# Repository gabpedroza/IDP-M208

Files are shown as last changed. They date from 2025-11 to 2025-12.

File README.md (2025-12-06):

# M208 IDP repository
Please read this file for important setup instructions

This branch has the code that actually ran in the robot, which can be read in /IDP/modules. The file graph_model.py is an exception: it has about 7 lines that were reconstructed from memory, since these very last changes were not saved. They are very likely to be faithful.
## Prerequisites
- Thonny
- Git

## Setup Instructions
### Thonny
- Download Thonny from https://thonny.org/
- Open Thonny > bottom right > Select Interpreter > MicroPython (Raspberry Pi Pico)

### VSCode
- Unsure if this works.
- To setup:
`code --install-extension ms-python.python`
`code --install-extension visualstudioexptteam.vscodeintellicode`
`code --install-extension ms-python.vscode-pylance`
`code --install-extension paulober.pico-w-go`

- To launch: `export PICO_SDK_PATH=/home/pi/pico/pico-sdk` -->
`code`

## Version Control Practices
1. Commit every significant change. If unsure, err on the side of committing too much rather than too little.
2. Add a helpful commit message to EVERY commit so that people know what is going on/what has been changed.
3. Work on your own branch and resolve conflicts carefully before merging into `main`.

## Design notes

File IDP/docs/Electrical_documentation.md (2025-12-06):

## Motors
### Linear actuator
The motors connections are wired so that the red wire should connect to the pin labelled 1. Otherwise, it is plug and play.
## Sensors
### I2C ports testing
Using the very reliable VL53L0X, all I2C pin pairs (not connected to motors) were tested. All of them work, besides:
- Pins 31 & 32 (GP 26 & GP 27) don't seem to work. The sensor spits an error:
```
Traceback (most recent call last):
  File "<stdin>", line 33, in <module>
  File "<stdin>", line 11, in test_vl53l0x
  File "libs/VL53L0X/VL53L0X.py", line 114, in __init__
  File "libs/VL53L0X/VL53L0X.py", line 164, in init
  File "libs/VL53L0X/VL53L0X.py", line 149, in _flag
  File "libs/VL53L0X/VL53L0X.py", line 145, in _register
  File "libs/VL53L0X/VL53L0X.py", line 137, in _registers
OSError: [Errno 110] ETIMEDOUT
```

Since both I2C channels seem to work, this shouldn't be a problem.

`TODO`: check if pins 31 & 32 work with other sensors.
### VL53L0X ToF distance sensor (left because good)
It works out of the box. The I2C address is 0x29, which conflicts with TCS3462S. Hence it is a good strategy to turn off the colour sensor when it's not in use.

The sensor seems to have a constant offset of about 25mm (that is, the real distance is generally 25mm less than it detects), but is otherwise more accurate than my measurements. It can detect distances reliably from 4cm all the way to about 17.5cm, assuming its offset is consistent (which seemed very likely).
### TCS3472S colour sensor
It needs pull-up resistors on SDA (green) and SCL; $\mathrm{2.2k}\Omega$ works. Its address is 0x29 (you can tell the pull up is not working if the Pico picks up an address that is not 0x29 = 41).

The sensor needs to be around 3mm from the box (ideally closer but not further) to reliably detect the colour of it.

The sensor was extremely volatile as tested. The numbers were stable, but it would recurrently disconnect from I2C, hence, a fault-tolerant code is needed, e.g. (adapted from handout):

```python
from machine import Pin, SoftI2C, I2C
from libs.tcs3472_micropython.tcs3472 import tcs3472
from utime import sleep

def test_tcs3472():
    i2c_bus = I2C(id=0, sda=Pin(8), scl=Pin(9)) 
    tcs = tcs3472(i2c_bus)

    while True:
        try:
            print("Light:", tcs.light())
            print("RGB:", tcs.rgb())
            sleep(1)
        except:
            try:
                tcs = tcs3472(i2c_bus)
            except:
                sleep(1)

if __name__ == "__main__":
    test_tcs3472()
```
`TODO`: tests other pull up values, test colour range with the proper blocks.
### TTL line sensors
They are plug and play. They require pull-down resistors, which the Pico can supply internally (`Pin(#pin_number#, Pin.IN, Pin.PULL_DOWN)` from the handout).

They (number is at the moment codified by the number of knots on their wires) were measured to have the following characteristics (distances measured from the PCB):

1. TTL #1 could detect the back of the breadboard from a 2.7cm distance.
2. TTL #2 could detect the back of the breadboard from a 2.9cm distance.
3. TTL #3 could detect the back of the breadboard from a 2.65cm distance.
4. TTL #4 could detect the back of the breadboard from a 2.8cm distance.

The sensors light up with a blue LED on their back when they see something white. This could potentially be useful when diagnosing robot problems.
### TMF8701 Distance sensor (front)
It works out of the box, with I2C address 65.
We are using it in proximity mode as it's being used as the front sensor for detecting the distance to the box. The robot will need to move a bit further after the sensor reports distance being zero as it can't actually detect low distances below 5mm. Colour sensor must be 3mm away from the box to work

It has three sensing modes: proximity, distance, and combine. It also supports built-in calibration. 

1. In the proximity mode, the sensor can only detect object up to 9cm from it. It was most accurate around the 5cm mark, and it was found it doesn't have a constant offset (though it didn't deviate by more than 7mm). It could detect objects within that accuracy all the way to basically touching the sensor.

2. In the distance mode, it could detect objects up to about 17cm away. Again, the offset seemed to shift with distance, and it seemed most accurate at the 8cm mark. The offset could vary my more than 1.5cm. It could detect objects well up to touching distance.

3. In the hybrid (combined) mode, it seemed to be no better than the distance mode. 8cm mark looked accurate, but it had varying offset elsewhere. The range seems to be longer than the proximity mode, but shorter than the distance mode.

### Ultrasonic sensor (right because bad)
The sensor is plug and play, but must be connected to a port with ADC. Adapting the code from [here](https://docs.micropython.org/en/latest/rp2/quickref.html) and [here](https://wiki.dfrobot.com/URM09_Ultrasonic_Sensor_(Gravity_Analog)_SKU_SEN0307), it can thus be written:
```python
from machine import ADC, Pin
from time import sleep
adc = ADC(Pin(28))     # create ADC object on GP number
        
while True:
    msum = 0
    for _ in range(10):
        msum += adc.read_u16()*390/65535 #12-bit ADC
        #390 seems to give accurate numbers 
        sleep(0.04) #below the 30 Hz max polling rate
    print(msum/10)

```
The sensor fluctuates a lot and very drastically between measurements (e.g. by 3cm). By averaging e.g. the last 10 measurements as above, the sensor still has acceptable throughput and is much more stable. 

Since it behaves in such a simple way, the error is strongly dependent on the multiplying constant chosen. `3900` gives about 5 mm of error from 40mm all the way to 24mm. This can be made better with finer tuning. Tuning has not been done yet.
Thresholds for detecting boxes on the track reliably have also not been done and need to be tuned once we are ready to use the sensor.

## LED circuit Biasing
### Red LED and colour sensor with BJT
- 3.3V output from Pico servo port (pins 2 and 3) is VDD
- Pulldown resistor 10k between emitter and input
- 2.7k resistor at base
- 150Ohm resistor at collector
- colour sensor goes in parallel with LED + collector resistor
- SDA and SCL have 2.2k pullup resistors

## Amber LED Oscillator circuit
- Use CD4093B as a schmidt trigger.
- Connect Pin 1 to GPIO output of Pico
- Pin 14 to Vcc (3.3V) and pin 7 to GND
- Pin 2 to 120Ohm resistor in series with amber LED and ground
- 580k resistor betweeen pins 3 and 2.
- 2 3.3uF capacitors between pin 2 and GND.
- The time constant is proportional to the product of the 580k resistor and the effective capacitance.

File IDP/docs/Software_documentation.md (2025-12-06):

# Software
1. [Algorithms](#algorithms)
    1. [General outline](#general-outline)
    2. [Sensing lines](#sensing-lines)
    3. [PID](#pid)
    4. [Radical turn](#radical-turn)
    5. [Appendix: the BFS algorithm](#appendix-the-bfs-algorithm) 

2. [Class specifications](#class-specifications)
    1. [Junction](#junction)
    2. [Plant](#plant)
    3. [Follower](#follower)
## Algorithms
### General outline
The robot operates in 3 clearly distinct modes.
1. "ground": It circles around the ground floor of the arena, looking for boxes. It does so by checking with the left-hand side distance sensor. This is achieved through the `Follower.hunt_box` method (though it doesnt have a loop itself).
2. "second": It goes back and forth in the second floor, looking for boxes. In this case, it has to use sensors on both sides. This is also achieved through the `Follower.hunt_box` method.
3. Delivery: after picking up a box with `Follower.pick_ground_box`, follows a breadth-first algorithm to go between two specified nodes, using the `Follower.deliver_box` method. 

It starts on the ground mode, and momentarily switches to delivery mode on each detected box. After a set number of boxes are picked up and delivered, it switches to second mode, and goes back to delivery whenever it finds a box. After finding the last boxes, it delivers itself to the start area through the delivery mode. It auto-detects when to go home inside the `Follower.hunt_box` method, and returns with the method `Follower.go_home`. 
### Sensing lines
The robot averages out a set of line measurements to produce a list of values on which to act. White and black are hence defined through a threshold. This smoothes out possible small glitches in the sensors. 

The two middle sensors only care about PID (straight line following), as written in `Follower.pid`. The two external sensors only care about node detection. Node detection is a two-step process, as written in `Follower.detect_radical_turn`:
 1. If any external sensor detects something white, it records that. The node has not yet been detected.
 2. After a specified period of time since this first detection (currently 150ms), it checks again, with both sensors. The outcome of this measurement gives the output of node detection.

This is to ensure even a misaligned robot can detect a cross (+) pattern correctly.  
### PID
It's actually a poportional controller for following straight lines. It's executed whenever a node is not detected.
### Radical turn
A radical turn is the behaviour of the robot upon detecting a node. It doesn't necessarily involve a physical turn; it just means the robot turns off its PID mind and follows whatever is specified for that node in that mode, as descrbed in the modes dictionary. 
### Appendix: the BFS algorithm
A graph is a set of nodes connected by edges (which are, in our case, straight segments). The node picture of the arena naturally gives way to thinking of it as a graph.

Given two nodes in a graph, the problem of finding the best path between them, using edges as roads, is non-trivial. The breadth-first algorithm finds the path that minimises path length as computed by the number of nodes in it. It does so as follows, using the help of a queue (all nodes start with infinite distance):
1. Given a node $A$, check all of its neighbours $B_i$
2. If some node $B_j$ has infinite distance, update its distance as $d(B_j) = d(A) + 1$ and push it into the queue.
3. After all neighbouring nodes $B_j$ have been checked, take the first node in the queue to be $A$ and go back to step 1.

The algorithm is kickstarted by picking the starting node to be $A$ and setting its distance to be 0. It then proceeds until the queue is empty. One can picture it as a contagious process where nearer nodes are infected first; thus it minimises distances according to node count.

In order to build a path between $P$ and $Q$ with it, one runs BFS starting at $P$, thus getting a list of the distance of all nodes to $P$. Then one starts at $Q$ and traces back the path: given a node $K$ in the path, the previous node must have had distance $d(K) - 1$. Since $Q$ is in the path, this reconstructs the shortest path recursively. (Of course this need not be *the* unique shortest path. Several paths can have the overall, minimum distance).

Alternatively, simply trust the `Follower._bfs` method works and don't touch it.
## Class specifications
### Junction
The `Junction` class is in the `graph_model.py` file. It models the features of the arena as nodes. A feature can be understood as any line pattern which is not plainly straight.

Each `Junction` instance has four sides, numbered from 0 to 3. They are absolute values, i.e. independent of `Junction` or robot orientation. If one looks at the arena so that the home (start) square is in its upper side, then the numbers can be understood to mean, from 0 to 3, East, North, West, and South, respectively. 
#### Attributes
A `Junction` instance has attributes:
- `self.shape`: Can be one of `"L"`, `"T"`, and `"+"`. It is only used for visualisation purposes (e.g. in the `Plant` method `print`).

- `self.node_number`: a unique `int` identifying the node. In particular, `Plant.nodes[node_number]` indexes the node on the arena.

- `self.connections`: a dictionary of `int : tuple(Junction, int)`. It conveys the connections between nodes. `junctionA.connections[3]==(junctionB, 1)` means that `junctionA` has its side `3` connected to side `1` of `junctionB`.

- `self.modes`: a dictionary of lists with keys `"ground"` and `"second"`. They are followed by the robot when hunting for boxes in the ground and second floor, respectively. For each mode, the list associated with its name is made of 4 entries, symbolising the behaviour of the robot when entering each one of the sides of the tile. For example, if the node has `mode["ground"]==["left", "front", "right", "backR"]`, then the robot is expected to turn left when entering side `0`, continue ahead when entering side `1`, turn right when entering side `2`, and do a 180 deg turn on its right when entering side `3`.
#### Constructor
The constructor takes a `shape` parameter, which can be `"T"`, `"L"`, or `"+"`, corresponding to the obvious types of line patterns.
#### `connect` method
Calling `junctA.connect(a, junctB, b)` connects node `junctA` to `junctB`, on the side `a` of the former and side `b` of the latter. Notice that it updates the `connections` dictionary of both `junctA` and `junctB` (i.e. it assumes the connection is bidirectional).

### Plant
The `Plant` class is in the `graph_model.py` file. Its instance represents the arena. 

#### Attributes 
- `self.nodes`: list of all the `Junction`s of the arena. Indexes are by node_number. 
- `self.boxes`: dictionary of `int : str` mapping node_number to the box colour associated with it. This is for testing and debugging only.
#### `print` method
This is for simulating the robot. It takes in (optionally) the current node of the robot as node_number, optionally its orientation, and an optional list of nodes. It then prints a picture of the arena with the current node and path highlighted.

#### `add_box` method
Adds a box with colour `colour` at node `node_number`. For debugging purposes only.

#### `init_nodes` metod
Creates all the `Junction` instances. The order of their creation is **critical** because that specifies the node_numbers. Changing a single line can potentially break everything. Additions should be done only in the end of the method, never in the middle. 

#### `init_MODE_connections` methods
Wires up the node connections for the nodes in the MODE floor. All connections are bidirectional, except for nodes 31 and 39, which are the `"T"` nodes at the end of the racks of the second floor. They have a ghost, uni-directional connection from their side 3 to side 3 of nodes 30 and 38, respectively. This is to make that odd 180 degree turn work seamlessly with the algorithms.

#### `init_MODE_modes` methods
Sets up the `mode` dictionary for each node involved in MODE. Notice that the second floor modes also involve the ground floor because the robot must be able to climb from the ground floor to the second floor after it's done with the former. They effectively specify the box-hunting path following.

#### Constructor
Calls all of the partial constructors above.

### Follower
The `Follower` class is in the `line_following.py` file. It represents the robot. Cf. the code for an explanation of most methods work together, and [Algorithms](#algorithms) above for their roles.
#### Attributes:
- `self.thresh`: The threshold value below which the average of a line sensor is considered black.
- `self.waiting`: flag that is crucial for the radial turn algorithm.
- `self.node` and `self.orientation`: store the current node_number and the current orientation of the robot.
- `self.plant`: is an instance of the `Plant` class.
- `self.landmark_map`: dictionary mapping box delivery or start square places to node_numbers.
- `self.box_count` and `self.box_colour`: hold the number of boxes delivered and the colour of the current box the robot may be holding, respectively. 
- `self.motorLeft`, `self.motorRight`, `self.lineSensors`, `self.linearActuator`, `self.frontDistance`, `self.colourSensor`, `self.button`, and `self.leftDistance`: self-explanatory; they are instances of their respective classes.

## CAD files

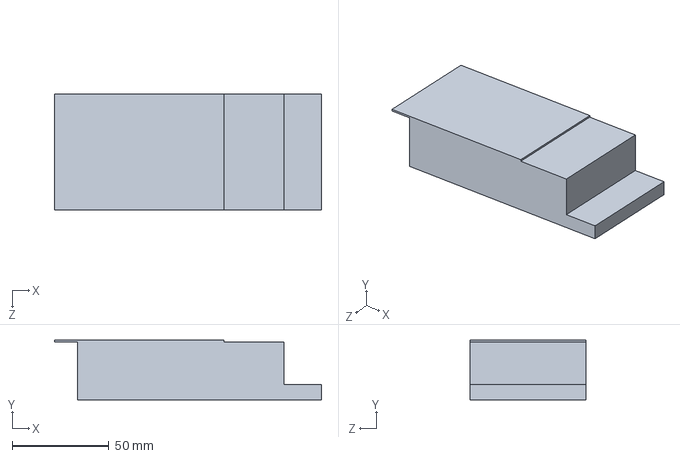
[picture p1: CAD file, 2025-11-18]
assembly_parts/picobox1.SLDPRT
138.0 x 31.0 x 60.0 mm

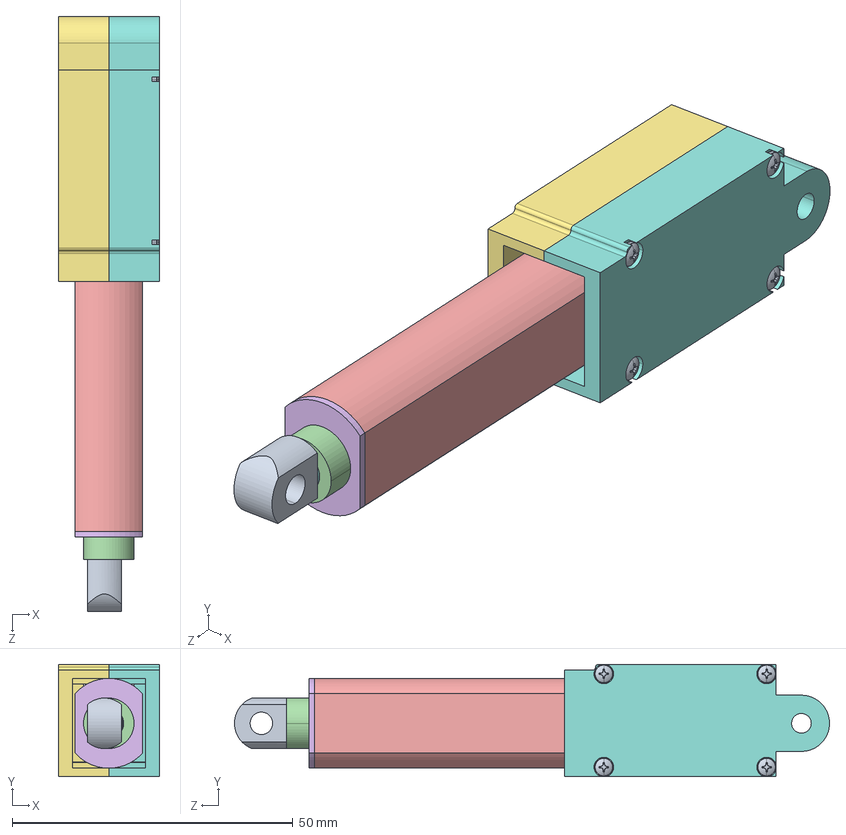
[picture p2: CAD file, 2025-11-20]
IDP/CAD/12V Linear Actuator.STEP
18.1 x 20.0 x 106.0 mm
MicroMotorN20_Predeterminado
MicroMotorN20Pieza1_Predeterminado
spur gear_iso_ISO - Spur gear 0.25M 14T 20PA 1.5FW ---S14A75H50L1.0N x 2
MicroMotorN20Pieza2_Predeterminado
MicroMotorN20Pieza3_Predeterminado
spur gear_iso_ISO - Spur gear 0.25M 19T 20PA 1FW ---S19A75H50L1.0N x 2
spur gear_iso_ISO - Spur gear 0.25M 12T 20PA 3.5FW ---S12A75H50L1.0N
spur gear_iso_ISO - Spur gear 0.25M 22T 20PA 1FW ---S22A75H50L1.0N
spur gear_iso_ISO - Spur gear 0.25M 22T 20PA 1.7FW ---S22A75H50L1.0N
spur gear_iso_ISO - Spur gear 0.25M 11T 20PA 2FW ---S11A75H50L1.0N
MicroMotorN20Suj1_Predeterminado
MicroMotorN20Suj2_Predeterminado
MicroMotorN20Pieza4_Predeterminado
MicroMotorN20Tornillo_Predeterminado x 2
Lead Screw
Shaft
Shaft Enclosure
Motor Enclosure
MirrorMotor Enclosure
92000A006_Passivated 18-8 Stainless Steel Pan Head Phillips Screws_92000A006 x 4

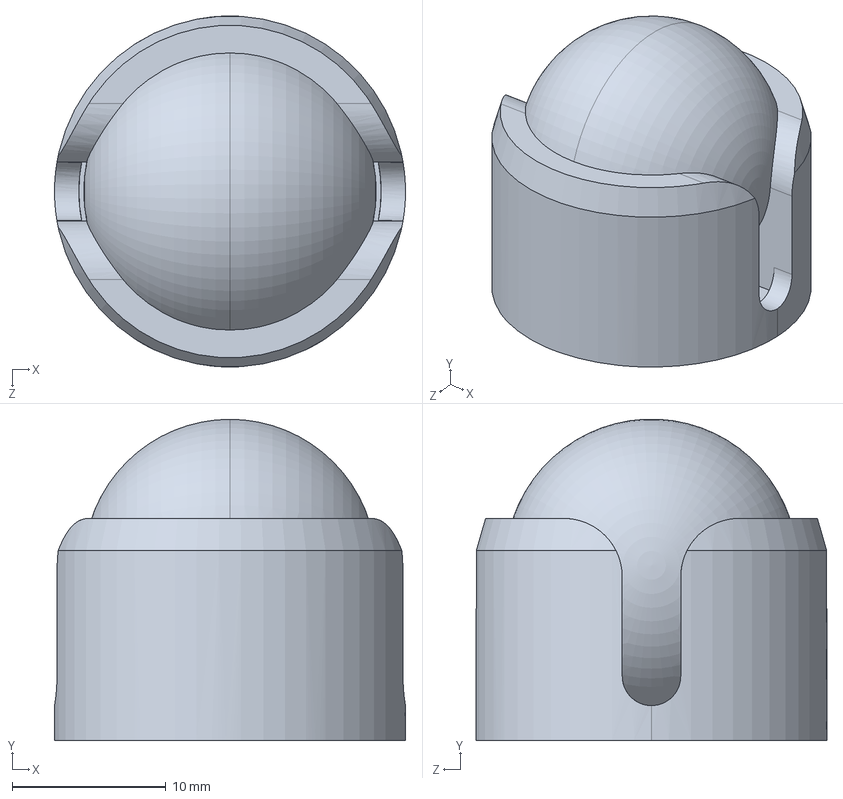
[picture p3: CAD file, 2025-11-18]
assembly_parts/pololu-ball-caster-with-0-750in-metal-ball.SLDPRT
22.9 x 20.9 x 22.9 mm

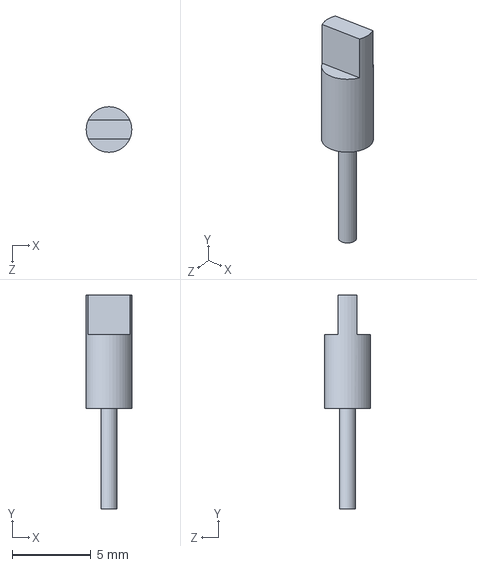
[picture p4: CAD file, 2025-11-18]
IDP/CAD/actiatorMicroMotorN20Pieza4.SLDPRT
2.90 x 13.6 x 2.90 mm

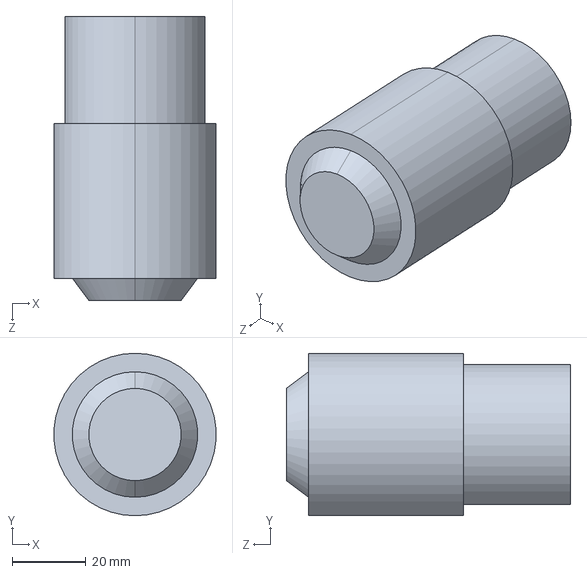
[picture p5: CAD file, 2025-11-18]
assembly_parts/motor-body.SLDPRT
43.9 x 44.0 x 77.0 mm

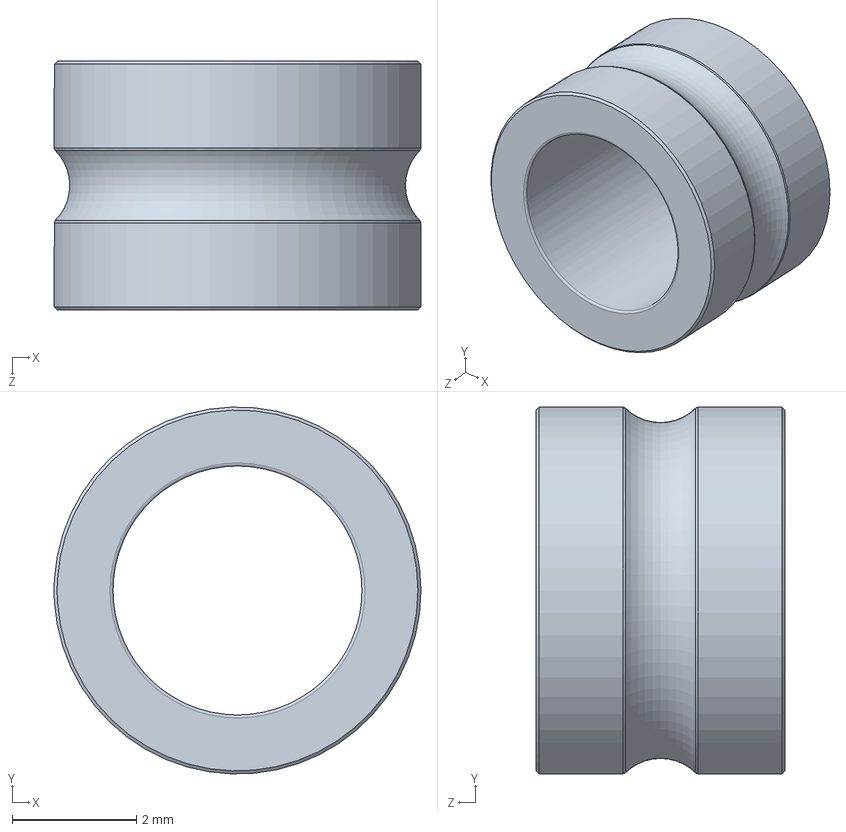
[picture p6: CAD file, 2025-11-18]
IDP/CAD/actiatorBody5.SLDPRT
5.90 x 5.90 x 4.00 mm

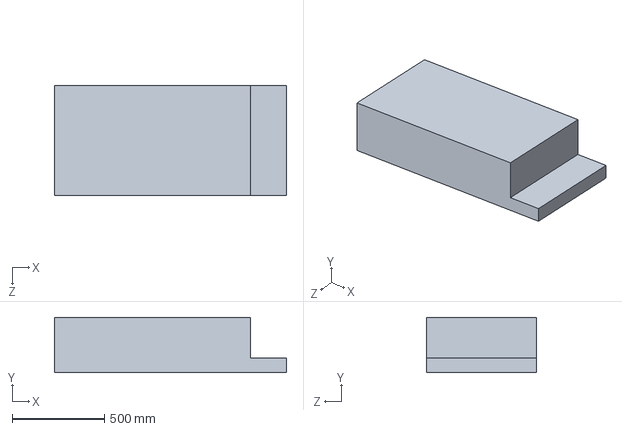
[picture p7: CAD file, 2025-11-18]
assembly_parts/picobox.SLDPRT
1260.0 x 300.0 x 600.0 mm

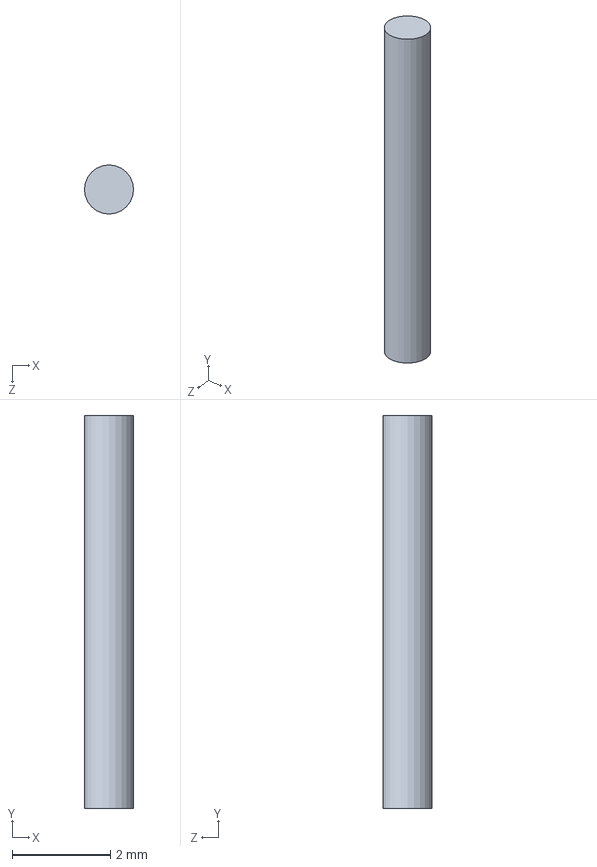
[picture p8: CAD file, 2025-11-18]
IDP/CAD/actiatorMicroMotorN20Suj2.SLDPRT
1.00 x 8.00 x 1.00 mm

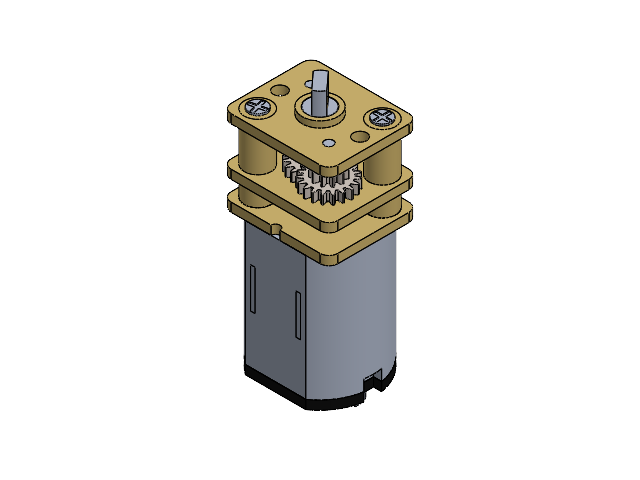
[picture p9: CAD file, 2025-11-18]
IDP/CAD/actiatorEnsamblajeMicroMotorN20.SLDASM
actiatorMicroMotorN20
actiatorMicroMotorN20Pieza1
spur gear_iso x 8
actiatorMicroMotorN20Pieza2
actiatorMicroMotorN20Pieza3
actiatorMicroMotorN20Suj1
actiatorMicroMotorN20Suj2
actiatorMicroMotorN20Pieza4
actiatorMicroMotorN20Tornillo x 2

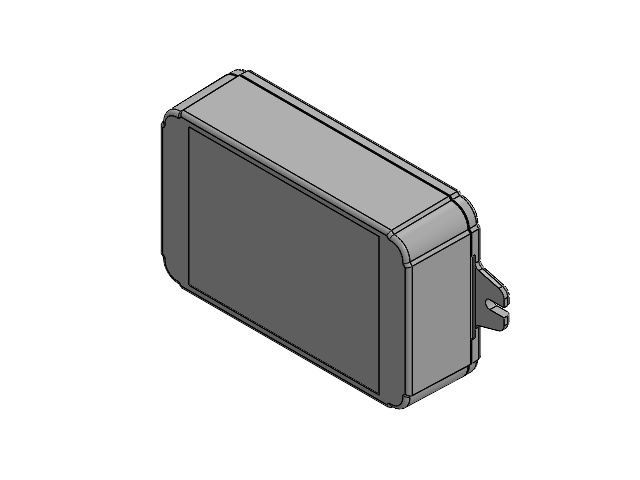
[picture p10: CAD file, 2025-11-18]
assembly_parts/Battery_box_RL6165-F.SLDASM
RL6165-B v0 130902_1.stp
RL6175-TF v0 130902_1.stp
(screw M2.6X 20mm FH)_1.stp x 4

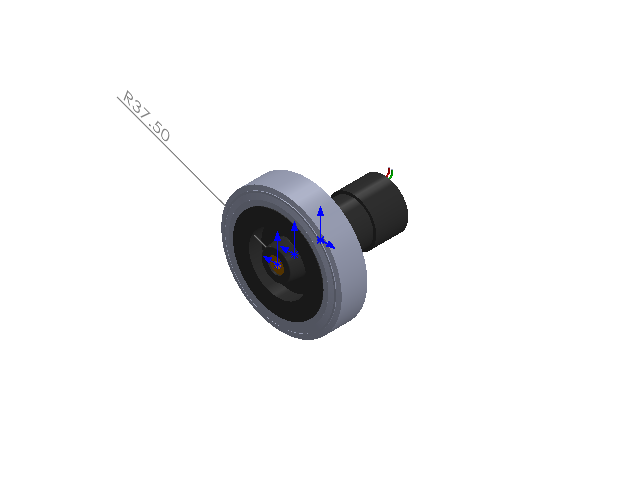
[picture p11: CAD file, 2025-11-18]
assembly_parts/new-drive-assy-75.SLDASM
new-motor-20.prt
wheel_75_tyre.prt
wheel_75_inner.prt
sleeve.prt

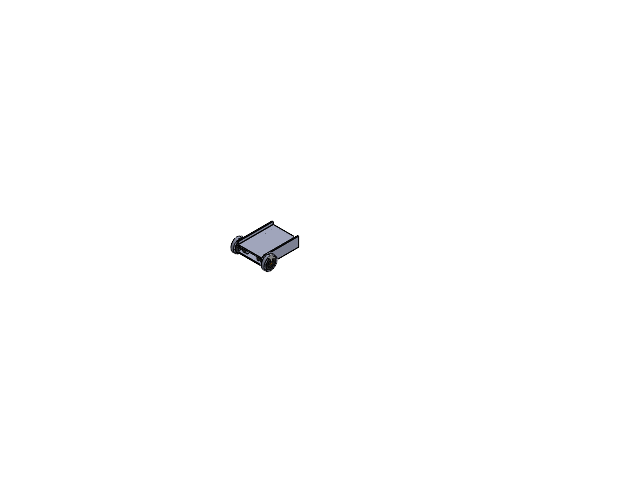
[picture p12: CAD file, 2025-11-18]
assembly_parts/baseassembly.SLDASM
base
new-motor-20.prt x 2
wheel_75_tyre.prt x 2
wheel_75_inner.prt x 2
sleeve.prt x 2
RL6165-B v0 130902_1.stp
RL6175-TF v0 130902_1.stp
(screw M2.6X 20mm FH)_1.stp x 4

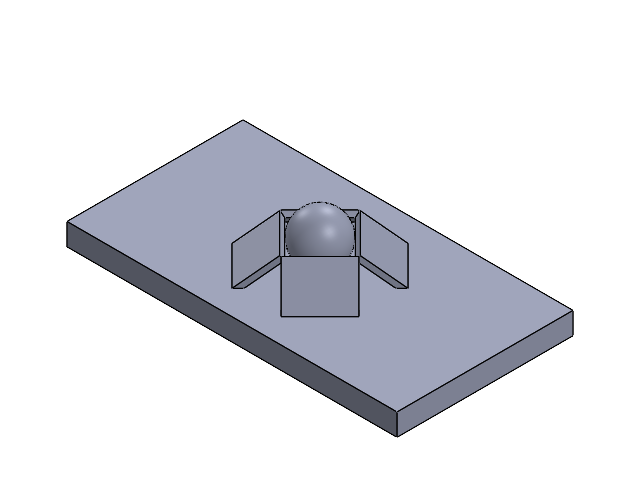
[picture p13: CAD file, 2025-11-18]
IDP/CAD/ball_assem.SLDASM
ball_holder
ball

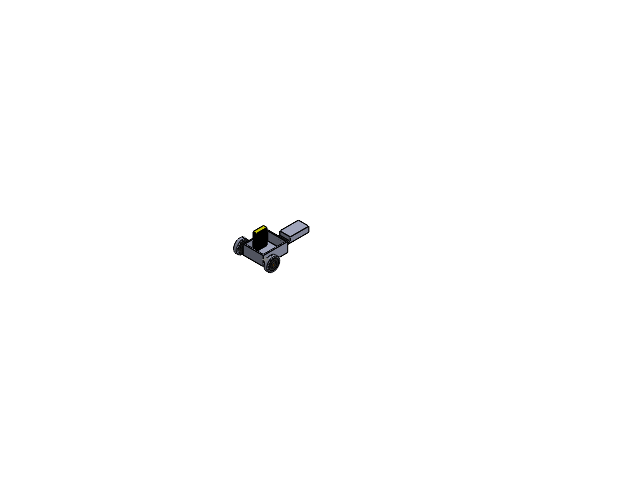
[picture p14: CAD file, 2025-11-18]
assembly_parts/baseassembly1.SLDASM
base
new-motor-20.prt x 2
wheel_75_tyre.prt x 2
wheel_75_inner.prt x 2
sleeve.prt x 2
picobox1
battery

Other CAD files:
assembly_parts/baseassembly2.SLDASM
IDP/CAD/actiatorBall Bearing.SLDASM
assembly_parts/2_75_Wheel_276-1496.SLDASM
IDP/CAD/baseassembly2.SLDASM
IDP/CAD/12V Linear Actuator.SLDASM
IDP/CAD/actiator7804K129_Stainless Steel Ball Bearing.SLDPRT
IDP/CAD/actiator92000A006_Passivated 18-8 Stainless Steel Pan Head Phillips Screws.SLDPRT
IDP/CAD/actiatorBody2.SLDPRT
IDP/CAD/actiatorBody3.SLDPRT
IDP/CAD/actiatorBody4.SLDPRT
IDP/CAD/actiatorLead Screw.SLDPRT
IDP/CAD/actiatorMicroMotorN20.SLDPRT
IDP/CAD/actiatorMicroMotorN20Pieza1.SLDPRT
IDP/CAD/actiatorMicroMotorN20Pieza2.SLDPRT
IDP/CAD/actiatorMicroMotorN20Pieza3.SLDPRT
IDP/CAD/actiatorMicroMotorN20Suj1.SLDPRT
IDP/CAD/actiatorMicroMotorN20Tornillo.SLDPRT
IDP/CAD/actiatorMirrorMotor Enclosure.SLDPRT
IDP/CAD/actiatorMotor Enclosure.SLDPRT
IDP/CAD/actiatorShaft Enclosure.SLDPRT
IDP/CAD/actiatorShaft.SLDPRT
IDP/CAD/ball.SLDPRT
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

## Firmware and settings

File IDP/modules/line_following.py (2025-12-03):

'''Main module for line following logic'''
from modules.drive_motors import DCMotor
from modules.line_sensors import LineSensors
from modules.graph_model import Plant
from modules.linear_actuator import LinearActuator
from modules.distance_sensors import FrontDistance, LeftDistance
from modules.colour import ColourSensor
from modules.button import Button
from machine import SoftI2C, I2C, Pin
from utime import sleep, ticks_ms, sleep_ms
class Follower:
    '''Figure out the situation the robot is in at a single time step, and apply correction. '''
    def __init__(self, pins_assignment : list, thresh= 0.5, correction_functions = [lambda x: x, lambda x: x]):
        '''set variables on initialization. Pin ordering: motorLeft x 2, motorRight x2, (far left,left,right, far right) TTL, actuator dir, actuator PWM, front dist sda, front dist scl, colour sda, colour scl, colour enable, button, left dist sda, left dist scl
            correction_functions order: left, right'''
        #ultrasound gp27, adc1; button gp25
        #store inputs from the line sensors. These will already be processed to be binary (1 or 0). Format: front, left, right, rear
        self.thresh = thresh
        self.motorLeft = DCMotor(pins_assignment[0], pins_assignment[1], correction_functions[0])
        self.motorRight = DCMotor(pins_assignment[2], pins_assignment[3], correction_functions[1])
        self.lineSensors = LineSensors(pins_assignment[4], pins_assignment[5], pins_assignment[6], pins_assignment[7])
        self.linearActuator = LinearActuator(pins_assignment[8], pins_assignment[9])
        print(f"{pins_assignment[10]}, {pins_assignment[11]}")
        #self.frontDistance = FrontDistance(I2C(id=0,sda=pins_assignment[10], scl=pins_assignment[11], freq=100000),30)
        self.button = Pin(pins_assignment[15], Pin.IN, Pin.PULL_DOWN) #will use this for interrupt handling
        self.leftDistance = LeftDistance(I2C(id=0, sda=Pin(pins_assignment[16]), scl=Pin(pins_assignment[17])), box_thresh_mm=280)
        self.activated = False
        self.amber_led = Pin(pins_assignment[18], Pin.OUT)
        
        #colour sensor activation
        enabler = Pin(pins_assignment[14], Pin.OUT)
        enabler.high()
        sleep_ms(3)
        #self.colourSensor = ColourSensor(I2C(0, sda=Pin(pins_assignment[12]), scl=Pin(pins_assignment[13]), freq=400000), enable_pin=pins_assignment[14])
        enabler.low()

        self.waiting= 0
        self.node = 1
        self.orientation = 1
        self.plant = Plant()
        self.landmark_map = {"red":40, "yellow":41, "green":43, "blue":44, "home":42}
        self.box_count = 0
        self.box_colour = "red"
        #TODO: set inputs from other sensors

    def detect_radical_turn(self, sensor_data):
        """Detects whether a node has been found
           Takes in sensor_data [far left, left, right, far right]
           Returns list[bool] representing whether sensor [left, right] has seen a radical (node-like) turn
        """
        radical_turn = [False, False]
        for s in [0, 3]:
            if sensor_data[s] > self.thresh and self.waiting == 0: #first detection, start timer
                self.waiting = ticks_ms()
        if self.waiting != 0 and ticks_ms() - self.waiting >= 150: #check if sensors see white
            if sensor_data[0] > self.thresh:
                radical_turn[0] = True
            if sensor_data[3] > self.thresh:
                radical_turn[1] = True
            self.waiting = 0
               
        return radical_turn

    def pid(self, sensor_data):
            """It's actually a proportional controller. """
            error = sensor_data[2] - sensor_data[1]
            self.motorLeft.forward(70 + 30*error)
            self.motorRight.forward(70 - 30*error)
            
    def slow_pid(self, sensor_data):
            """It's actually a slower proportional controller. """
            print("doing slow pid")
            error = sensor_data[2] - sensor_data[1]
            self.motorLeft.forward(50 + 40*error)
            self.motorRight.forward(50 - 40*error)
    

    def hunt_box(self, sensor_data, mode):
        '''
        Takes in sensor_data and decides what to do based on the mode algorithm and the current state of the robot.
        Behaviour at nodes can be inferred from their modes[mode] list, in the index of the robot orientation
        '''
        
        radical_turn = self.detect_radical_turn(sensor_data)

        if not radical_turn[0] and not radical_turn[1]:
            self.pid(sensor_data)
        else:
            self._turn(self.plant.nodes[self.node].modes[mode][self.orientation])

            #The robot is basically performing a depth-first search. After entering a node, it updates itself to match that node
            #NB the orientation was updated in the _turn function
            next_node = self.plant.nodes[self.node].connections[self.orientation]
            self.node, self.orientation = next_node[0].node_number, next_node[1]

    def _bfs(self, node_start, node_end):
        """
        Given a start node and an end node, returns the path between them that minimises node count, as a list of (node, orientation). 
        Orientation is the side of the next node in the path (that is, if x A y -- z B, then the path lists (y,B) after (x A))
        """
        #simple BFS
        distances = {}
        distances[node_start] = 0
        to_visit = [self.plant.nodes[node_start]]
        while len(to_visit) > 0:
            current_node = to_visit[0]
            to_visit = to_visit[1:]
            for n, ori in current_node.connections.values():
                if n.node_number not in distances.keys():
                    distances[n.node_number] = distances[current_node.node_number] + 1
                    to_visit.append(n)
        #backtracks the BFS starting from the end node. The previous node will be the one with -1 the distance of the current node
        end_distance = distances[node_end]
        path = [node_end]
        c_n = self.plant.nodes[node_end]
        while c_n.node_number != node_start:
            for my_ori, pairs in c_n.connections.items():
                n, ori = pairs
                if distances[n.node_number] == distances[c_n.node_number] - 1:
                    path.append((n, (ori+2)%4))
                    c_n = n
                    break
        path[0] = (self.plant.nodes[node_end], (path[1][0].connections[path[1][1]][1]+2)%4)
        return path[::-1] #since we built the path by tracing back distances, the list is in the reverse order
    
    def pick_ground_box(self):
        """What the robot does when it has identified a box and needs to deliver it. and then return to path.
        Starts from when the box was identified (so the first thing is turn left) and ends having returned all the way to the path with box in tow"""
        #turn left
        self.box_count += 1
        self._risky_turn("left") #we can make this more modular later to account for 2nd floor right turns
        #prepare the fork for slotting in. Assume we are already at 0 extension
        #sleep(999999)
        print("linear actuator preare")
        #sleep(9999999999)
        self.linearActuator.prepare_fork()
        '''
        for i in range(10):
            for j in range(10):
                self.lineSensors.get_new_values()
            avg = self.lineSensors.get_averages()
            self.pid(avg)
        '''
        
        arrived = False
        #until we have arrived, keep following the line and checking distance
        walk_time = ticks_ms()
        while not arrived:
            #get data from line sensors and do pid for line following
            for i in range(10):
                self.lineSensors.get_new_values()
            avg = self.lineSensors.get_averages()
            self.slow_pid(avg)
            #self.walk(0.6, 100)
            #arrived=True
            #check distance for arrival
            #distance = self.frontDistance.get_distance()
            #distance < self.frontDistance.arrival_distance or 
            if (ticks_ms() - walk_time > 1700):
                print(arrived)
                arrived = True #on next loop the while loop will be bypassed
        
        #self.walk(0.8)
        self.walk(0.1,0)
        #having arrived, we are 5 mm away (must check if this is enough). we need to be 3mm away. so walk a tiny bit more
        #sleep(999999)
        #self.walk(0.2) #try 0.2s of walking

        #activate colour sensor
        #determine colour, save this value in the instance for use in other functions
        #self.box_colour = self.colourSensor.get_colour() #this takes a second (literally 1 second). and handles enable and disable
        self.box_colour = 'red'

        #pick up box using linear actuator
        print("box lifty")
        self.linearActuator.lift_box()

        #reverse all the way to the junction then rotate clockwise 90 degrees. Now we're done and line following takes over to deliver box
        self.walk(1.7, -50)
        #self._rotate(direction="right", deg=90)
        self.node -= 2
        print("onto delivery")
        

    def deliver_box(self):
        '''Delivers box and returns to the same spot, oriented with the main line.'''
        #follow path to destination
        goal_node = self.landmark_map[self.box_colour]

        print(f'going to {goal_node} because box is {self.box_colour}')
        path = self._bfs(self.node, goal_node)
        print([(i[0].node_number, i[1]) for i in path])
        while(self.orientation != path[0][1]):
            self._rotate() #rotates while the robot is not aligned with the needed start direction of the path
            sleep(1)
            print(f"{self.node}, {self.orientation}")
        self.walk(0.2, -100)
        sleep(1)
        for n, o in path[1:]: #it will go over each node in the path
            radical_turn = [False,False]
            print(f"{self.node}, {self.orientation}")
            while(not radical_turn[0] and not radical_turn[1]): #while the node has not been reached, 
                for i in range(10):
                    self.lineSensors.get_new_values()
                avg = self.lineSensors.get_averages()
                radical_turn = self.detect_radical_turn(avg)
                if not radical_turn[0] and not radical_turn[1]: #pid
                    self.pid(avg)
                else: #but update the sensors. if the node has been reached, act on it
                    if o == (self.orientation+1)%4:
                        self._turn("right")
                    elif o==(self.orientation-1)%4:
                        self._turn("left")
                    else: #if you should go straight ahead, do nothing
                        pass
                    self.node = n.node_number #update to the next node
                    self.orientation = o

        #is in the node that leads to the colour
        #drop off the box
        while True or (ticks_ms() - time_now <= 8000):
            for i in range(10):
                    self.lineSensors.get_new_values()
            avg = self.lineSensors.get_averages()
            self.pid(avg)
            if self.detect_radical_turn(avg) != [False, False]:
                self.walk(0.01, 0)
                break
        #sleep(999)
        self.linearActuator.drop_box()
        print('droppy boxy')
        self.walk(0.5, -100)
        
        #reset the linear actuator to full retraction
        print('retracty')
        self.linearActuator.reset_fork()

        #time to go back. Basically same algorithm as above
        if self.box_count != 4: #if all boxes collected, go home
            path = self._bfs(self.node, path[0][0].node_number)
            print('looking for more boxes')
            while(self.orientation != path[0][1]):
                print('rotating')
                self._rotate("right")
            for n, o in path[1:]:
                my_orientation = (o+2)%4 #the storage is beginning *-> *-> .... * end. Hence to know the reverse direction I must now the orientation
                #at the other end of the arrow. 
                radical_turn = [0,0]
                while(not radical_turn[0] and not radical_turn[1]):
                    for i in range(10):
                        self.lineSensors.get_new_values()
                    avg = self.lineSensors.get_averages()
                    radical_turn = self.detect_radical_turn(avg)
                    if not radical_turn[0] and not radical_turn[1]:
                        self.pid(avg)
                    else:
                        if my_orientation == (self.orientation+1)%4:
                            self._turn("right")
                        elif my_orientation==(self.orientation-1)%4:
                            self._turn("left")
                        else:
                            pass
                        self.node = n.node_number
                        self.orientation = my_orientation
                #theoretically should be back now
            self.orientation = (self.orientation + 2)%4
        else:
            print('going home')
            self.go_home()
    def _rotate(self, direction="left", deg=90):
        '''rotates around the axis of the wheels a sepcified amount.'''
        if direction == "left":
            self.motorLeft.reverse(100)
            self.motorRight.forward(100)
            sleep(0.70*deg/90)
            self.orientation = (self.orientation-deg//90)%4
        elif direction == "right":
            self.motorLeft.forward(100)
            self.motorRight.reverse(100)
            sleep(0.70*deg/90)
            self.orientation = (self.orientation+deg//90)%4
        self.walk(0.001,0)
    def go_home(self):
        '''This is a modified version of the deliver-box method but without the coming back part.'''
        goal_node = self.landmark_map["home"]
        path = self._bfs(self.node, goal_node)
        self.plant.print(self.node, path=path)
        while(self.orientation != path[0][1]):
            self._rotate()
        for n, o in path[1:]:
            radical_turn = [0,0]
            while(not radical_turn[0] and not radical_turn[1]):
                for i in range(10):
                    self.lineSensors.get_new_values()
                avg = self.lineSensors.get_averages()
                radical_turn = self.detect_radical_turn(avg)
                if not radical_turn[0] and not radical_turn[1]:
                    self.pid(avg)
                else:
                    if o == (self.orientation+1)%4:
                        self._turn("right")
                    elif o==(self.orientation-1)%4:
                        self._turn("left")
                    else:
                        pass
                    self.node = n.node_number
                    self.orientation = o
                    self.plant.print(self.node, path=path)
        print("DONE!!!!")
    def _turn(self, direction):
        '''Models the behaviour of the robot on a node. 
        direction can be "left", "right", "backR" (for 180 deg on the right side), "backL", or "front".
        The orientation of the robot is automatically updated.'''
        if(direction == "left"):
            self.orientation = (self.orientation-1)%4
            self.motorRight.forward(100)
            self.motorLeft.reverse(15)
            sleep(1.3)
        elif(direction == "right"):
            self.orientation = (self.orientation+1)%4
            self.motorLeft.forward(100)
            self.motorRight.reverse(15)
            sleep(1.3)
        elif(direction == "backR"):
            self._rotate("right", 180)
            self.orientation = (self.orientation+2)%4
            self.node -= 1
        elif direction == "backL":
            self._rotate("left", 180)
            self.orientation = (self.orientation+2)%4
            #self.node -= 1
        else:
            self.orientation = (self.orientation + 2)%4
            
        self.motorRight.forward(0)
        self.motorLeft.forward(0)
        
    def _risky_turn(self, direction):
        '''Does the old-school sharp turn'''
        self.walk(0.4)
        if direction == "left":
            self.motorRight.forward(100)
            self.motorLeft.reverse(100)
            self.orientation = (self.orientation-1)%4
        if direction == "right":
            self.motorLeft.forward(100)
            self.motorRight.reverse(100)
            elf.orientation = (self.orientation+1)%4
        sleep(0.7)
        self.walk(0.1, 0)

    def walk(self, delay, speed = 100):
        '''Moves forwards (speed > 0) or backwards (speed < 0). Can stop with speed == 0.
        Stops after the specified delay.'''
        if(speed > 0):
            self.motorLeft.forward(speed)
            self.motorRight.forward(speed)
        else:
            print("backwards")
            self.motorLeft.reverse(-1*speed)
            self.motorRight.reverse(-1*speed)
        sleep(delay)
        self.motorLeft.forward(0)
        self.motorRight.forward(0)

if __name__ == '__main__':
    robot = Follower([4, 5, 7, 6,14, 11,10,8, 0,1,20,21,16,17,18, 19,20,21], thresh = 0.5)
    '''
    print("imhere")
    for i in range(50 + 1):
        robot.linearActuator.set(1, i)
        sleep(0.01)
    sleep(5)
    for i in range(50 + 1):
        robot.linearActuator.set(1, 50 - i)
        sleep(0.01)
    robot.pick_ground_box()
    '''
    robot.walk(3, -100)

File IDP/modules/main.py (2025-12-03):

'''Main module for line following logic'''
from modules.drive_motors import DCMotor, LinearActuator
from modules.line_sensors import LineSensors
from modules.line_following import Follower
from machine import Pin
from modules.distance_sensors import LeftDistance
from utime import sleep

BOX_CHECK_SAMPLES = 3
BUTTON_PIN = 28
#motor left, motor right, far left, left, right, far right, linear actuatorx2, front distance, colour, colour enable, button, left distance
robot = Follower([4, 5, 7, 6,14, 11,10,8, 0,1,20,21,16,17,18, BUTTON_PIN,20,21, 27], thresh = 0.5)
print("imhere")




# global variable that determines whether the robot is on or off
activated = False
button = Pin(BUTTON_PIN,Pin.IN, Pin.PULL_DOWN)


# function that is called when button is pressed
def handle_interrupt(pin):
    global activated
    print("Button pressed!")
    if not activated:
        activated = True
    else:
        activated = False
        robot.walk(0.1,0)
        machine.reset()
    
            


# calls the interrupt function when button is pressed
button.irq(trigger=Pin.IRQ_RISING, handler=handle_interrupt)

# have to check if the script goes back to here, or if continues from where it was interrupted

def main():
    #wait for button
    while not activated:
        robot.amber_led.off()
        sleep(0.01)
    
    #now we have activated
    #start led
    for i in range(1):
        robot.linearActuator.reset_fork()
    robot.walk(0.8)
    robot.amber_led.on()

    box=False
    prev_node = 4

    while True:
        #main loop to run if we are activated
        if activated:
            #make sure led is on
            robot.amber_led.on()
            #time1 = ticks_ms()
            for i in range(10):
                robot.lineSensors.get_new_values()
            #print(ticks_ms() - time1)
            #sleep(9999)
            avg = robot.lineSensors.get_averages()
            #print(avg)
            if box and (robot.detect_radical_turn(avg) in [[True, False], [False, True]]):
                robot.pick_ground_box()
                robot.deliver_box()
                #robot.node -= 1
            
            else:
                robot.hunt_box(avg, "ground")

            #nodes 5 to 10 and 16 to 21 are the nodes where we could find box
            #BUT we want to stop checking shortly after reaching the last nodes, otherwise we will be checking up until the end of the straight
            if (robot.node in range(5,11) or robot.node in range(16,22)) and not box:
                print(robot.node)
                if robot.node > prev_node:
                    #when we reach a new node, stop the robot
                    robot.walk(0.1,speed=0)
                    #check distance 3 times for box detection
                    for _ in range(3):
                        dist=robot.leftDistance.get_current_distance()
                        sleep(0.03)
                        print(dist)
                    box = robot.leftDistance.determine_if_box(n_samples=BOX_CHECK_SAMPLES) #need to tune this according to how much time we have to see boxes (esp start and end box)
                    if box:
                        print("box found!")
                        #if we find a box, we now need to get it and return to the path which is all handled by one handy function
                        robot.pick_ground_box()
                        #now we need to deliver it. robot already knows what the colour is and will go accordingly.
                        robot.deliver_box()
                        #now the robot has delivered the box and is back where it started when it initially detected box. So on the next run of the loop we are just going to keep going from the top
                        box = False
                prev_node = robot.node
        else:
            #stop robot but stay in main loop
            robot.walk(0.1,0)
            #need to turn off led too
            robot.amber_led.off()
               

main()

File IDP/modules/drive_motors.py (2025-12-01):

from machine import Pin, PWM
from utime import sleep

class DCMotor:
    def __init__(self, dirPin, PWMPin, correction_function):
        '''Initialises the servo motor at (dirPin, PWMPin). correction_function is a calibration function that normalises both motors to the same 1-100 scale'''
        self.mDir = Pin(dirPin, Pin.OUT)  # set motor direction pin
        self.pwm = PWM(Pin(PWMPin))  # set motor pwm pin
        self.correction_function = correction_function
        self.pwm.freq(1000)  # set PWM frequency
        self.pwm.duty_u16(0)  # set duty cycle - 0=off
        
    def off(self):
        
        self.pwm.duty_u16(0)
        
    def forward(self, speed=100):
        self.mDir.value(0)                     # forward = 0 reverse = 1 motor
        self.pwm.duty_u16(int(65535 * self.correction_function(speed) / 100))  # speed range 0-100 motor

    def reverse(self, speed=30):
        self.mDir.value(1)
        self.pwm.duty_u16(int(65535 * speed / 100))

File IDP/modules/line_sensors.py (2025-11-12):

'''collect data from line sensors and format to a binary list.'''
#NOTE: line sensor data comes in from a GPIO port and will be either logic HIGH or LOW. HIGH => light (on line) and LOW otherwise

from machine import Pin

class LineSensors:

    #static variables for data across samples
    front_data: list[int] = []
    left_data: list[int] = []
    right_data: list[int] = []
    rear_data: list[int] = []

    '''for collecting data from line sensors'''
    def __init__(self, front_pin, left_pin, right_pin, rear_pin) -> None: #collect port values for all sensors. Use GPXX number rather than jumper number
        #initialize pin instances from each sensor
        self.front_sensor = Pin(front_pin, Pin.IN, Pin.PULL_DOWN) #TODO: Determine whether to pull up or down
        self.left_sensor = Pin(left_pin, Pin.IN, Pin.PULL_DOWN)
        self.right_sensor = Pin(right_pin, Pin.IN, Pin.PULL_DOWN)
        self.rear_sensor = Pin(rear_pin, Pin.IN, Pin.PULL_DOWN)

    def get_new_values(self) -> None:
        '''Appends current values (0 or 1) from all 4 sensors and adds to respective lists'''
        #poll sensors for values. 1 for white and 0 for black
        self.front_data.append(self.front_sensor.value())
        self.left_data.append(self.left_sensor.value())
        self.right_data.append(self.right_sensor.value())
        self.rear_data.append(self.rear_sensor.value())
        return
        
    def get_averages(self) -> list[float]:
        '''average the values from all the sensors and clear data, call this after a certain number of loops of get_new_values'''
        #error handling for if we try to average an empty list
        if self.front_data == [] or self.left_data == [] or self.right_data == [] or self.rear_data == []:
            raise Exception("sensors have not collected any data")

        else: #main averaging
            front_sum = 0
            for x in self.front_data:
                front_sum += x
            front_average = front_sum / len(self.front_data)

            left_sum = 0
            for x in self.left_data:
                left_sum += x
            left__average = left_sum / len(self.left_data)

            right_sum = 0
            for x in self.right_data:
                right_sum += x
            right_average = right_sum / len(self.right_data)

            rear_sum = 0
            for x in self.rear_data:
                rear_sum += x
            rear_average = rear_sum / len(self.rear_data)

            #now clean up the static lists to empty them
            self.front_data, self.left_data, self.right_data, self.rear_data = [], [], [], []

            #now return the averages
            return [front_average, left__average, right_average, rear_average]

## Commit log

2025-11-11 built line following input logic and line sensor input logic
2025-11-11 minimal sensor testing for tcs --- which was a headache tbh. no code changed
2025-11-11 all sensors tested, but the buttons, i reckon
2025-11-11 capitalized the word note don't make commits this small guys it was just bugging my ocd
    [line_sensors.py]
2025-11-11 linear actuator
2025-11-12 Fix typo in motor connection instructions
    Corrected 'show' to 'should' in motor connection instructions.
2025-11-12 refactor(line sensors): average data across samples
2025-11-12 motors copy and paste from handout with minor correction adjustment
    [board_v1.kicad_pcb, board_v1.kicad_sch]
2025-11-12 type specification for sensor data
2025-11-12 small correction linear actuator
    [drive_motors.py]
2025-11-12 pid code works. needs urgent clean up
2025-11-13 documented oscillator circuit
2025-11-14 electrical documentation of colour sensor
2025-11-17 Add files via upload
    acitsiot
    [12V Linear Actuator.SLDASM, actiator7804K129_Stainless Steel Ball Bearing.SLDPRT, actiator92000A006_Passivated 18-8 Stainless Steel Pan Head Phillips Screws.SL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]
2025-11-17 Add files via upload
    ball spinny
    [ball.SLDPRT, ball_assem.SLDASM, ball_holder.SLDPRT]
2025-11-17 colour testing (not working yet)
    [colour.py]
2025-11-17 colour sensor now working!
2025-11-17 colour sensor code documentation
2025-11-18 finished tuning colour sensor
2025-11-18 minor fix and code ready for prod
    [colour.py]
2025-11-18 documented sensor testing and selection
2025-11-19 ground working
2025-11-19 working front sensor and imported code for all distance sensors
2025-11-20 left sensor done
2025-11-20 done with distance sensor coding. But have not calibrated ultrasonic yet.
2025-11-20 fixed minor mistake in pickGroundmode
    [line_following.py]
2025-11-20 outline for linear actuator class
2025-11-22 linear actuator class makes it easy to extend and retract fork
2025-11-22 updated constructor to include actuator pins
2025-11-22 - added distance, colour, actuator to constructor - wrote box pickup/dropoff and colour identification logic - changed arrival distance to account for the need to extend the fork first
2025-11-24 redid box picking and actuator logic based on how it actually works next step is to teset everything with robot
2025-11-24 super simple button class
2025-11-24 fixed button class to make the button state saved
    [button.py]
2025-11-25 el button
2025-11-25 fixed code written by someone else
    [line_following.py]
2025-11-25 wrote button logic larenwce
2025-11-25 added left distance sensor to follower class
2025-11-25 minor correction to incorrect comment
    [line_following.py]
2025-11-25 reset left distance sensor data when found box
    [distance_sensors.py]
2025-11-26 reworked button interrupt logic and made a test file
    [button.py, main.py]
2025-11-26 interrupt fix thank you gabreild
    [main.py]
2025-11-28 fixed duplication of enabling and disabling colour sensor now handled by get_colour() so no need for that in line following code.
    [colour.py, line_following.py, test_tcs3472.py]
2025-12-01 button working!
2025-12-01 made progress with many things. robot now working but the problem is it freezes
    [distance_sensors.py, drive_motors.py, line_following.py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]
